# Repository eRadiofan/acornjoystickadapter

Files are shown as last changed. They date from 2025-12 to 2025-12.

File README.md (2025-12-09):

Joystick Adapter for Acorn Archimedes Computers
===============================================

KiCad project for an Archimedes joystick adapter. Derived from an initial design by **Ian Haylock** that plugs externally into the computers parallel port and enables two Atari style joysticks to be plugged in. Software must be installed on the Archimedes to recognize the adapter, see ``software`` folder. Full details and pictures can be found in this Stardot Forum [thread](https://stardot.org.uk/forums/viewtopic.php?f=16&t=24492). See ``release`` folder for latest version manufcatoring files along with a BOM file.

This fork contains some improvements by Radiofan, including shorter traces, adjustments for (slightly cheaper) connectors, use of 0805 resistors and through-hole capacitors (common stock).



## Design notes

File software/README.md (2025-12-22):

JoyStick.zip
=============

Orginal **ArcWeld Joystick Adapter** schematic in !Draw format and driver Modules from Ian Haylock. This software and circuit design only seems to exist [here](http://legacy.huber-net.de/Joystick.zip) and is only referenced [here](https://forums.jaspp.org.uk/forum/viewtopic.php?p=3092#p3092). Unzip this on an Acorn Archimedes using apps such as !SparkFS. It is replicated here just in case that site disappears.

Module 3_31 has been modified to run on an A3000 fitted with 25MHz Arm 3, one additional software delay was added to cope with the slow transition of IO lines. Basic assembly source code is included.

**Author:** Ian Haylock

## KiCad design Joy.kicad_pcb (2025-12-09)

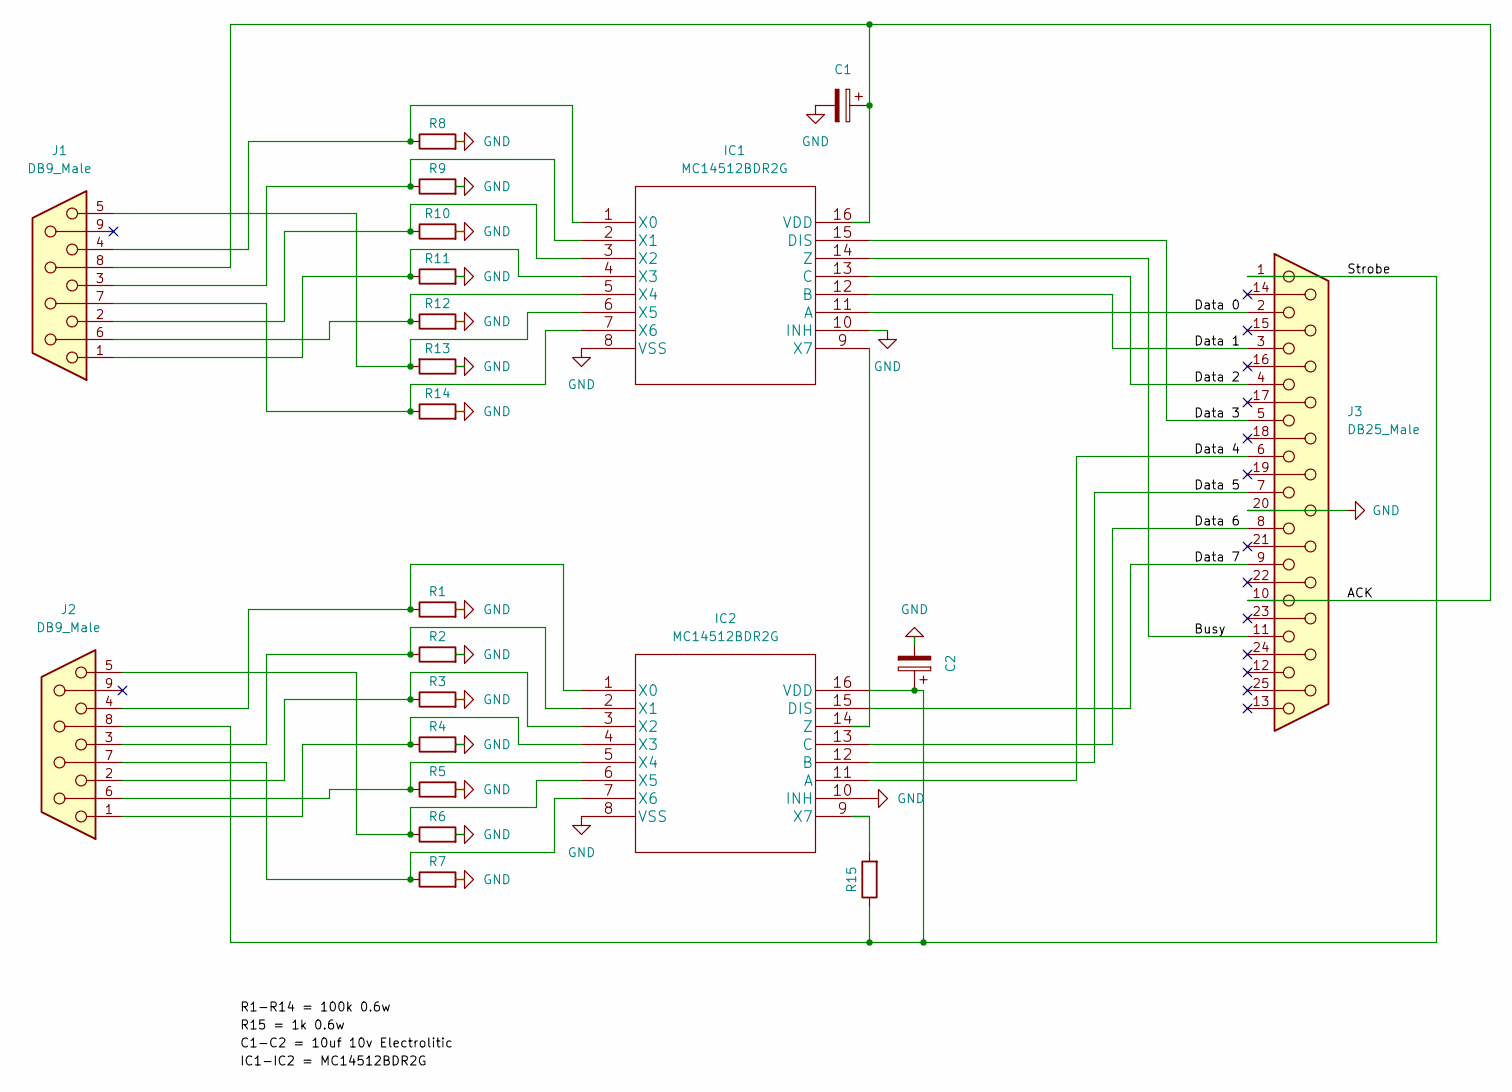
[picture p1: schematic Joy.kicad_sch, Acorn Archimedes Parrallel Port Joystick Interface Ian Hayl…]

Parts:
C1, C2: C_Polarized, 10uf Eletrolitic; CP_Radial_D5.0mm_P2.00mm
IC1, IC2: MC14512BDR2G; SOIC-16_3.9x9.9mm_P1.27mm
J1, J2: DB9_Male; 5747840-4
J3: DB25_Male; 5788794-1
R1, R2, R3, R4, R5, R6, R7, R8, R9, R10, R11, R12, R13, R14: 100k; R_0805_2012Metric_Pad1.20x1.40mm_HandSolder
R15: 1k; R_0805_2012Metric_Pad1.20x1.40mm_HandSolder

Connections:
/ACK: C1.1, IC1.16 (VDD), J1.8, J3.10
/Busy: IC1.14 (Z), J3.11
/Data 0: IC1.11 (A), J3.2
/Data 1: IC1.12 (B), J3.3
/Data 2: IC1.13 (C), J3.4
/Data 3: IC1.15 (DIS), J3.5
/Data 4: IC2.11 (A), J3.6
/Data 5: IC2.12 (B), J3.7
/Data 6: IC2.13 (C), J3.8
/Data 7: IC2.15 (DIS), J3.9
/Strobe: C2.1, IC2.16 (VDD), J2.8, J3.1, R15.1
GND: C1.2, C2.2, IC1.8 (VSS), IC1.10 (INH), IC2.8 (VSS), IC2.10 (INH), J3.20, R1.2, R2.2, R3.2, R4.2, R5.2, R6.2, R7.2, R8.2, R9.2, R10.2, R11.2, R12.2, R13.1, R14.2
unnamed: IC1.1 (X0), J1.4, R8.1
unnamed: IC1.2 (X1), J1.3, R9.1
unnamed: IC1.3 (X2), J1.2, R10.1
unnamed: IC1.4 (X3), J1.1, R11.1
unnamed: IC1.5 (X4), J1.6, R12.1
unnamed: IC1.6 (X5), J1.5, R13.2
unnamed: IC1.7 (X6), J1.7, R14.1
unnamed: IC1.9 (X7), IC2.14 (Z)
unnamed: IC2.1 (X0), J2.4, R1.1
unnamed: IC2.2 (X1), J2.3, R2.1
unnamed: IC2.3 (X2), J2.2, R3.1
unnamed: IC2.4 (X3), J2.1, R4.1
unnamed: IC2.5 (X4), J2.6, R5.1
unnamed: IC2.6 (X5), J2.5, R6.1
unnamed: IC2.7 (X6), J2.7, R7.1
unnamed: IC2.9 (X7), R15.2

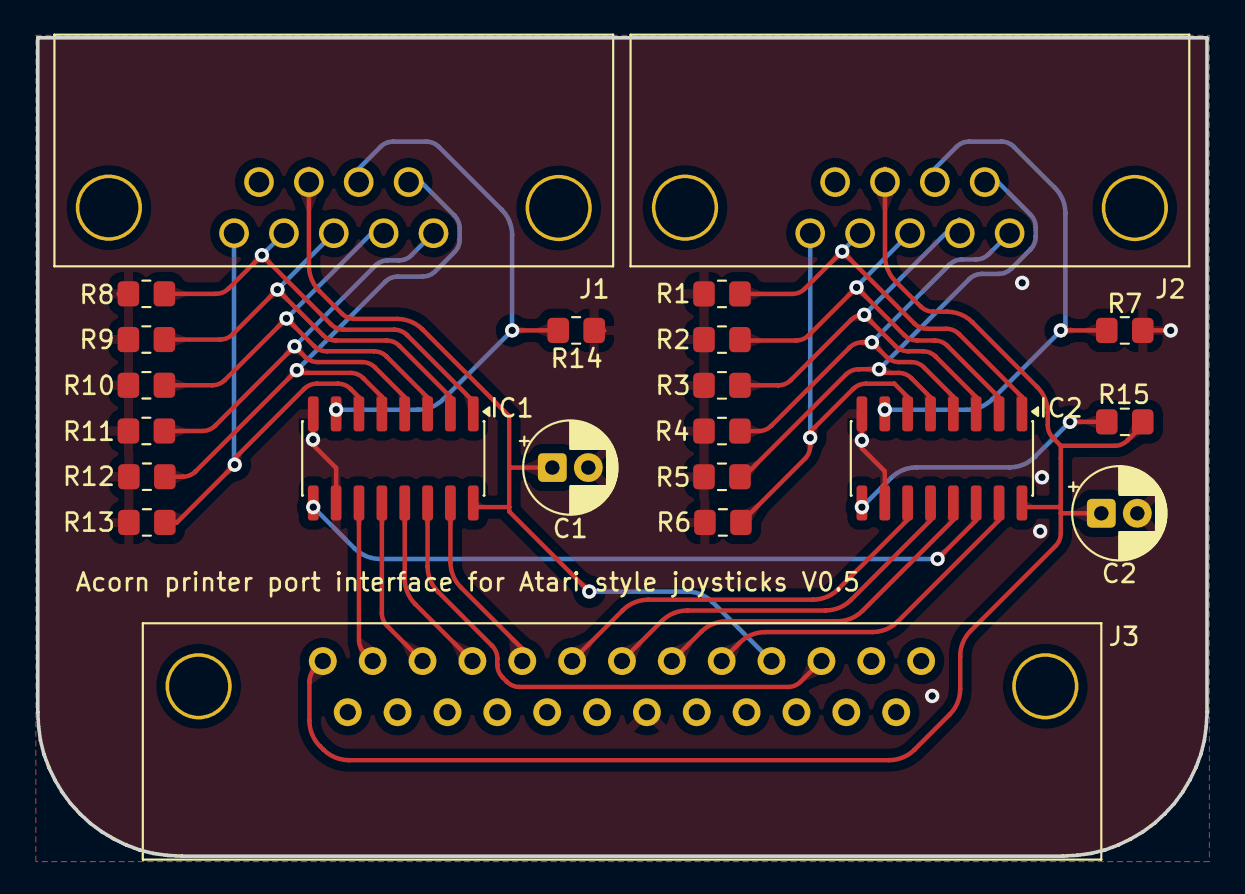
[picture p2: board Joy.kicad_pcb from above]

Board: 2 copper layers, 65.0 x 45.5 mm, 22 parts (0 on the bottom side), 28 nets.

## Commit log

2025-12-09 Capacitors now through-hole, resistors 0805, cheaper connectors
    [Joy-B_Cu.gbr, Joy-B_Mask.gbr, Joy-B_Paste.gbr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]
2025-12-22 Updated module
    [Joy.kicad_sch]
